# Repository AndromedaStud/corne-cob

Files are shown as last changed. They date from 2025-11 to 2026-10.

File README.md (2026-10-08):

# Corne Cob 🌽
*A modern Ergogen redesign of the popular Corne layout with personal modifications.*

<p align="center">
  Corne Cob Render
</p>

---

## Project Status
**Version:** v0.9  

> This version is still in development and may not be ready for production.

---

## Overview
**Corne Cob** builds on the [Corne](https://github.com/foostan/crkbd) layout and extends [Narkoleptika’s josukey](https://github.com/Narkoleptika/josukey) using [Ergogen](https://ergogen.xyz/).  
It’s designed with improved ergonomics, better hardware support, and a few quality-of-life enhancements.

---

## Key Features and Additions
Compared to **josukey** and similar corne layouts, Corne Cob includes:

- OLED display
- Larger battery for extended wireless life
- Angled case for improved typing comfort (not in v1.0)
- Separate left and right PCBs for easier assembly
- 1.5u thumb key support for more keycap options
- 6-column design (versus the standard 5-column Corne)
- Horizontal reset key for easier access
- North facing RGB for better choc keycap support

---

## Built With
- [Ergogen](https://ergogen.xyz/) — PCB designing 
- [KiCad](https://kicad.org/) — schematic and layout editing  
- [josukey](https://github.com/Narkoleptika/josukey) — base layout inspiration  

---

## Roadmap
- [X] Finalize v1 PCB layout
- [X] Setup price sheet for budget
- [ ] Test case fit and alignment  
- [ ] Validate power delivery and charging circuit  
- [ ] Release build guide and firmware configuration

---
## Parts List
Price estimate chart found [here](https://docs.google.com/spreadsheets/d/1HdLqQ5FFB6K92mRF0pi76wc0cOreWh93cLWDCBQdG54/edit?usp=sharing) <--

- Nice!Nano v2 2 [Microcontroller](https://typeractive.xyz/products/nice-nano)
- SSD1306 I2C IIC OLED 2 
- 1800 mah battery 2 (considering [PS3 Controller batteries](https://www.amazon.com/Replacement-Playstation-Controller-CECHZC2E-CECHZC2U-3/dp/B09726K2LC))
- Power Switch >2 [PCM12SMTR](https://www.digikey.com/en/products/detail/c-k/PCM12SMTR/1640112)
- Reset Switch >2 [EVQ-PUC02K](https://www.digikey.com/en/products/detail/panasonic-electronic-components/EVQ-PUC02K/286336)
- RGB LED >42 [S35353RGBSK6812MINID001](https://www.digikey.com/en/products/detail/home-run-tech/S35353RGBSK6812MINID001/25879535)
- Diode >42 [1N4148W](https://www.digikey.com/en/products/detail/smc-diode-solutions/1N4148W/6022450)
- Battery Adapter [S2B-PH-K-S](https://www.digikey.com/en/products/detail/jst-sales-america-inc/S2B-PH-K-S/926626)
- Choc v1 switches >42 [Pro Red](https://typeractive.xyz/products/choc-switches?variant=46024772387047)
- Choc v1 keycaps >42 
- Rubber Feet >8 [SJ5382](https://www.digikey.com/en/products/detail/3m/SJ5382/3866079)
- M2 screws >10
---

## Acknowledgements
Special thanks to **Narkoleptika** for the original [josukey](https://github.com/Narkoleptika/josukey) project, and to the **Ergogen** and **Corne** communities for their open-source contributions.

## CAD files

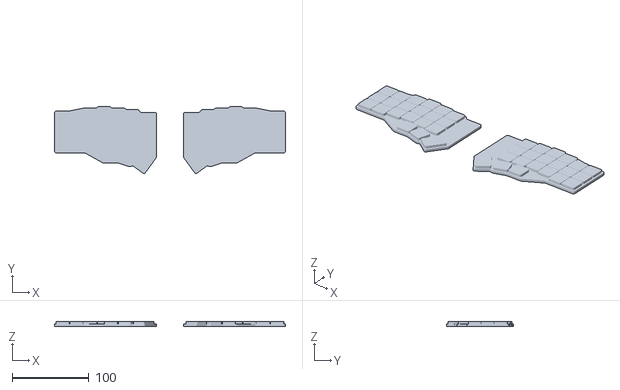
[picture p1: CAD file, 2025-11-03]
ergogen/cases/_model.stl
301.6 x 87.6 x 6.00

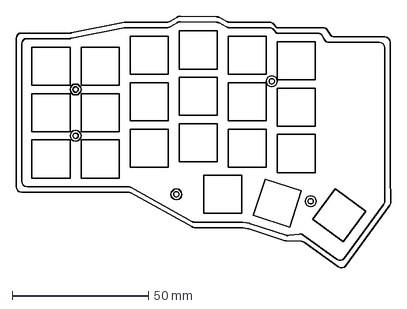
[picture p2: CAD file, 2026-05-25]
ergogen/outlines/preview2.dxf
137.5 x 92.6 mm

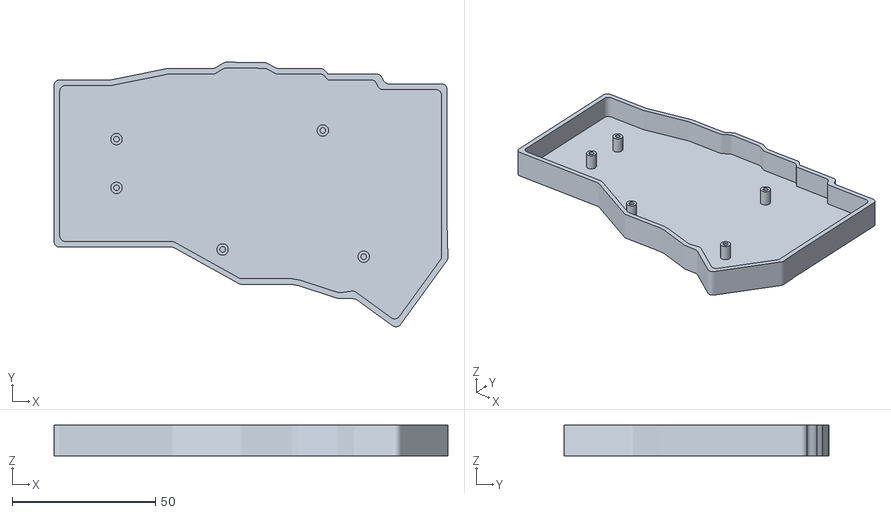
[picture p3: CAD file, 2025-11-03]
ergogen/cases/bottomCase.stl
137.5 x 92.4 x 10.8

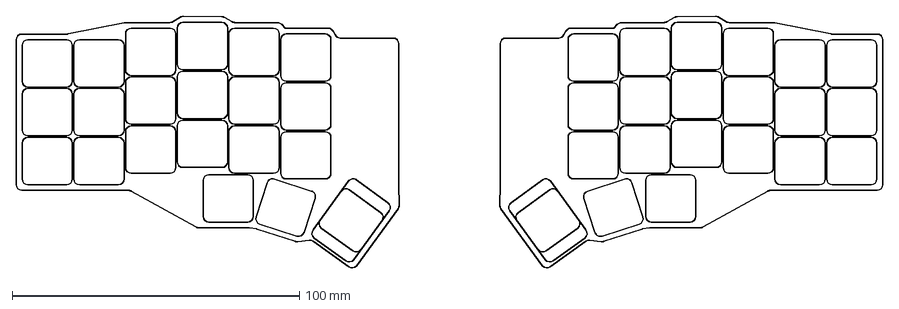
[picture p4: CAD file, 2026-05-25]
ergogen/outlines/preview.dxf
301.6 x 87.8 mm

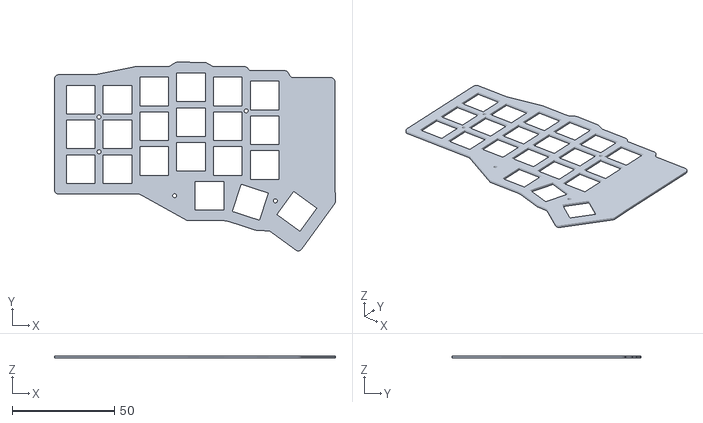
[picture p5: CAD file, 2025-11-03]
ergogen/cases/topCase.stl
137.5 x 92.4 x 1.20

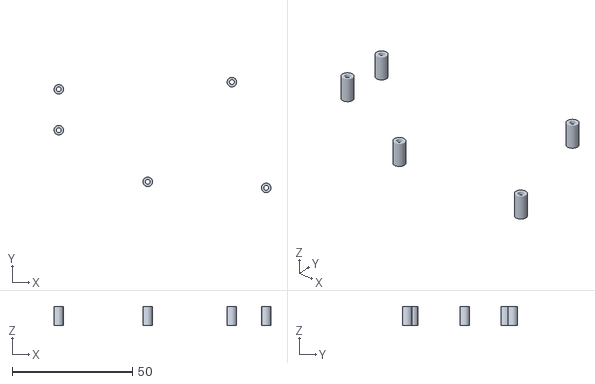
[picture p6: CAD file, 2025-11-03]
ergogen/cases/_holes.stl
90.3 x 48.0 x 8.00

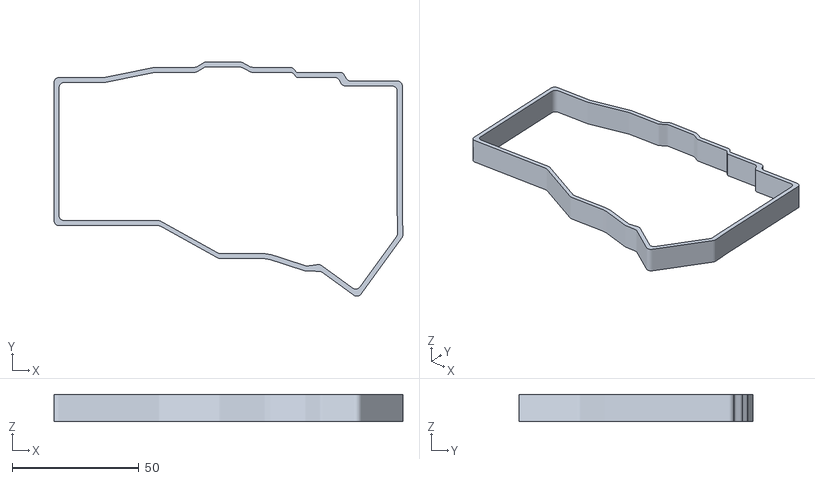
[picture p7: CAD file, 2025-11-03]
ergogen/cases/_bottomWall.stl
137.5 x 92.4 x 10.8

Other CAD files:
ergogen/cases/corne.stl

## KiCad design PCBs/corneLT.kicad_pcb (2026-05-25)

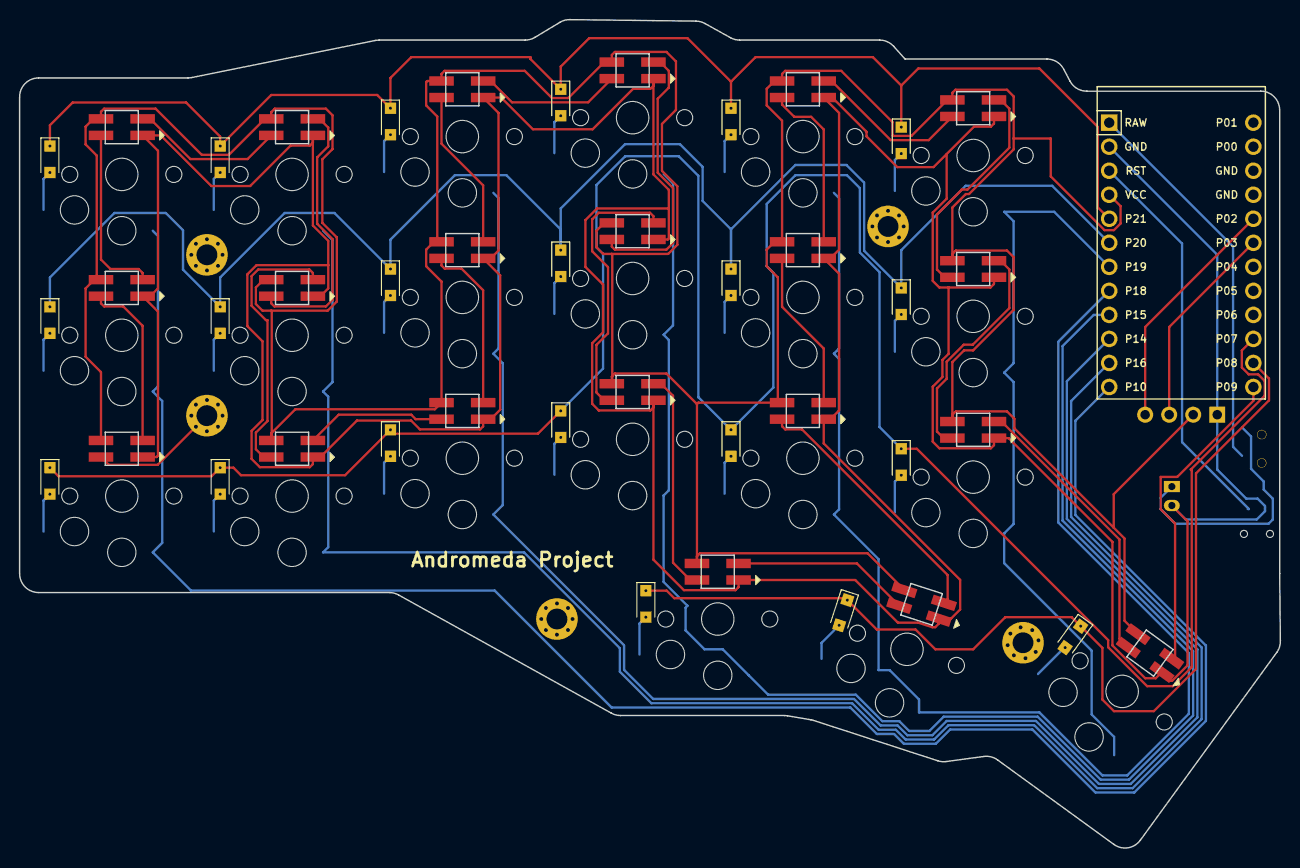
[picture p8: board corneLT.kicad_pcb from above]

Board: 2 copper layers, 133.3 x 87.6 mm, 73 parts (0 on the bottom side), 59 nets.

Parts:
B1: Panasonic_EVQPUL_EVQPUC
D1, D2, D3, D4, D5, D6, D7, D8, D9, D10, D11, D12, D13, D14, D15, D16, D17, D18, D19, D20, D21: Nexperia_CFP3_SOD-123W
JST1: JST_PH_S2B-PH-K_02x2.00mm_Angled
LED1, LED2, LED3, LED4, LED5, LED6, LED7, LED8, LED9, LED10, LED11, LED12, LED13, LED14, LED15, LED16, LED17, LED18, LED19, LED20, LED21: WS2812B
MCU1: ProMicro
OLED1: OLED; OLED_headers
S1, S2, S3, S4, S5, S6, S7, S8, S9, S10, S11, S12, S13, S14, S15, S16, S17, S18, S19, S20, S21: PG1350
T1: SPDT_C128955
_1, _2, _3, _4, _5: MountingHole_2.2mm_M2_Pad_Via

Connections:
GND: B1.1, JST1.2, LED1.3, LED2.3, LED3.3, LED4.3, LED5.3, LED6.3, LED7.3, LED8.3, LED9.3, LED10.3, LED11.3, LED12.3, LED13.3, LED14.3, LED15.3, LED16.3, LED17.3, LED18.3, LED19.3, LED20.3, LED21.3, MCU1.2, MCU1.15, MCU1.16, OLED1.1
P2: MCU1.17, OLED1.4
P3: MCU1.18, OLED1.3
P7: D1.1, D4.1, D7.1, D10.1, D13.1, D16.1, MCU1.22
P8: D19.1, D20.1, D21.1, MCU1.23
P9: LED21.4, MCU1.24
P10: MCU1.12, S1.1, S2.1, S3.1
P14: MCU1.10, S7.1, S8.1, S9.1
P15: MCU1.9, S10.1, S11.1, S12.1, S19.1
P16: MCU1.11, S4.1, S5.1, S6.1
P18: MCU1.8, S13.1, S14.1, S15.1, S20.1
P19: MCU1.7, S16.1, S17.1, S18.1, S21.1
P20: D2.1, D5.1, D8.1, D11.1, D14.1, D17.1, MCU1.6
P21: D3.1, D6.1, D9.1, D12.1, D15.1, D18.1, MCU1.5
RAW: MCU1.1, T1.2
RST: B1.2, MCU1.3
VCC: LED1.1, LED2.1, LED3.1, LED4.1, LED5.1, LED6.1, LED7.1, LED8.1, LED9.1, LED10.1, LED11.1, LED12.1, LED13.1, LED14.1, LED15.1, LED16.1, LED17.1, LED18.1, LED19.1, LED20.1, LED21.1, MCU1.4, OLED1.2
main_index_bottom: D13.2, S13.2
main_index_home: D14.2, S14.2
main_index_top: D15.2, S15.2
main_inner_bottom: D16.2, S16.2
main_inner_home: D17.2, S17.2
main_inner_top: D18.2, S18.2
main_middle_bottom: D10.2, S10.2
main_middle_home: D11.2, S11.2
main_middle_top: D12.2, S12.2
main_pinky2_bottom: D4.2, S4.2
main_pinky2_home: D5.2, S5.2
main_pinky2_top: D6.2, S6.2
main_pinky_bottom: D1.2, S1.2
main_pinky_home: D2.2, S2.2
main_pinky_top: D3.2, S3.2
main_ring_bottom: D7.2, S7.2
main_ring_home: D8.2, S8.2
main_ring_top: D9.2, S9.2
pos: JST1.1, T1.1
rgb_main_index_bottom: LED13.4, LED14.2
rgb_main_index_home: LED14.4, LED15.2
rgb_main_index_top: LED15.4, LED18.2
rgb_main_inner_bottom: LED16.4, LED21.2
rgb_main_inner_home: LED16.2, LED17.4
rgb_main_inner_top: LED17.2, LED18.4
rgb_main_middle_bottom: LED10.4, LED19.2
rgb_main_middle_home: LED10.2, LED11.4
rgb_main_middle_top: LED11.2, LED12.4
rgb_main_pinky2_bottom: LED4.4, LED7.2
rgb_main_pinky2_home: LED4.2, LED5.4
rgb_main_pinky2_top: LED5.2, LED6.4
rgb_main_pinky_bottom: LED1.4, LED2.2
rgb_main_pinky_home: LED2.4, LED3.2
rgb_main_pinky_top: LED3.4, LED6.2
rgb_main_ring_bottom: LED7.4, LED8.2
rgb_main_ring_home: LED8.4, LED9.2
rgb_main_ring_top: LED9.4, LED12.2
rgb_thumb_home_home: LED13.2, LED20.4
rgb_thumb_inner_home: LED19.4, LED20.2
thumb_home_home: D20.2, S20.2
thumb_inner_home: D19.2, S19.2
thumb_outer_home: D21.2, S21.2

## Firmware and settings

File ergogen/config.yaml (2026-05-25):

units:
    screwHead: 2
    screwShaft: 1
points:
    key.padding: cy
    zones:
        main:
            rows:
                bottom.row_net: P7
                home.row_net: P20
                top.row_net: P21
            columns:
                pinky:
                    key:
                        col_net: P10
                        spread: cx
                    rows:
                        bottom:
                            led_in: "rgb_{{name}}"
                        home:
                            led_in: "rgb_{{name}}"
                            led_out: rgb_main_pinky_bottom
                        top:
                            led_in: "rgb_{{name}}"
                            led_out: rgb_main_pinky_home
                pinky2:
                    key:
                        col_net: P16
                        spread: cx
                    rows:
                        bottom:
                            led_in: "rgb_{{name}}"
                            led_out: rgb_main_pinky2_home
                        home:
                            led_in: "rgb_{{name}}"
                            led_out: rgb_main_pinky2_top
                        top:
                            led_in: "rgb_{{name}}"
                            led_out: rgb_main_pinky_top
                ring:
                    key:
                        col_net: P14
                        stagger: 4
                        spread: cx
                    rows:
                        bottom:
                            led_in: "rgb_{{name}}"
                            led_out: rgb_main_pinky2_bottom
                        home:
                            led_in: "rgb_{{name}}"
                            led_out: rgb_main_ring_bottom
                        top:
                            led_in: "rgb_{{name}}"
                            led_out: rgb_main_ring_home
                middle:
                    key:
                        col_net: P15
                        stagger: 2
                        spread: cx
                    rows:
                        bottom:
                            led_in: "rgb_{{name}}"
                            led_out: rgb_main_middle_home
                        home:
                            led_in: "rgb_{{name}}"
                            led_out: rgb_main_middle_top
                        top:
                            led_in: "rgb_{{name}}"
                            led_out: rgb_main_ring_top
                index:
                    key:
                        col_net: P18
                        stagger: -2
                        spread: cx
                    rows:
                        bottom:
                            led_in: "rgb_{{name}}"
                            led_out: rgb_thumb_home_home
                        home:
                            led_in: "rgb_{{name}}"
                            led_out: rgb_main_index_bottom
                        top:
                            led_in: "rgb_{{name}}"
                            led_out: rgb_main_index_home
                inner:
                    key:
                        col_net: P19
                        stagger: -2
                        spread: cx
                    rows:
                        bottom:
                            led_in: "rgb_{{name}}"
                            led_out: rgb_main_inner_home
                        home:
                            led_in: "rgb_{{name}}"
                            led_out: rgb_main_inner_top
                        top:
                            led_in: "rgb_{{name}}"
                            led_out: rgb_main_index_top
        thumb:
            anchor:
                ref: main_index_bottom
                shift: [-0.5cx, -cy]
            rows.home.row_net: P8
            columns:
                inner.key:
                    col_net: P15
                    led_in: "rgb_{{name}}"
                    led_out: rgb_main_middle_bottom
                    spread: cx
                home.key:
                    col_net: P18
                    led_in: "rgb_{{name}}"
                    led_out: rgb_thumb_inner_home
                    spread: cx + 2
                    rotate: -18
                    stagger: -3.2
                outer.key:
                    col_net: P19
                    led_in: P9
                    led_out: rgb_main_inner_bottom
                    spread: cx
                    rotate: -36
                    stagger: -9.20
                    height: 1.5u
                    shift: [0.25u,0.25u]
    mirror: &mirror
        ref: main_inner_top
        distance: 100
outlines:
    _board_outline:
        -   what: polygon
            fillet: 2
            points:
                -   ref: thumb_outer_home
                    shift: [0.6cx, 0.8cy]
                -   ref: thumb_outer_home
                    shift: [0.6cx, -0.8cy]
                -   ref: thumb_outer_home
                    shift: [-0.4cx, -0.8cy]

                -   ref: thumb_home_home
                    shift: [0.4cx, -0.6cy]
                -   ref: thumb_home_home
                    shift: [-0.4cx, -0.6cy]

                -   ref: thumb_inner_home
                    shift: [0.4cx, -0.6cy]
                -   ref: thumb_inner_home
                    shift: [-0.6cx, -0.6cy]

                -   ref: main_pinky_bottom
                    shift: [1.6cx, -0.6cy]
                -   ref: main_pinky_bottom
                    shift: [0.6cx, -0.6cy]
                -   ref: main_pinky_bottom
                    shift: [-0.6cx, -0.6cy]

                -   ref: main_pinky_top
                    shift: [-0.6cx, 0.6cy]
                -   ref: main_pinky_top
                    shift: [0.4cx, 0.6cy]

                -   ref: main_ring_top
                    shift: [-0.5cx, 0.6cy]
                -   ref: main_ring_top
                    shift: [0.4cx, 0.6cy]

                -   ref: main_middle_top
                    shift: [-0.4cx, 0.61cy]
                -   ref: main_middle_top
                    shift: [0.4cx, 0.6cy]

                -   ref: main_index_top
                    shift: [-0.4cx, 0.6cy]
                -   ref: main_index_top
                    shift: [0.5cx, 0.6cy]

                -   ref: main_inner_top
                    shift: [-0.4cx, 0.6cy]
                -   ref: main_inner_top
                    shift: [0.5cx, 0.6cy]

                -   ref: main_inner_top
                    shift: [0.6cx, 0.4cy]
                -   ref: main_inner_top
                    shift: [1.8cx, 0.4cy]
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

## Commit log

2025-10-24 Added Ergogen file
    [corne.stl, preview.dxf]
2025-11-17 v0.9
    Ergogen files have been updated to final version but PCB has not been finalized.
2026-05-25 Fixed a variety of PCB issues and finalized layout
    [preview.dxf, preview2.dxf]
2026-05-25 v0.9
    PCB fixed and board design finalized, ready for test build
    [config.yaml]
2026-05-25 v9.1
    PCB finished and L/R schematics fixed
2026-05-25 v9.1
    test PCBs finished
    [corneLT.kicad_pcb, corneRT.kicad_pcb]
